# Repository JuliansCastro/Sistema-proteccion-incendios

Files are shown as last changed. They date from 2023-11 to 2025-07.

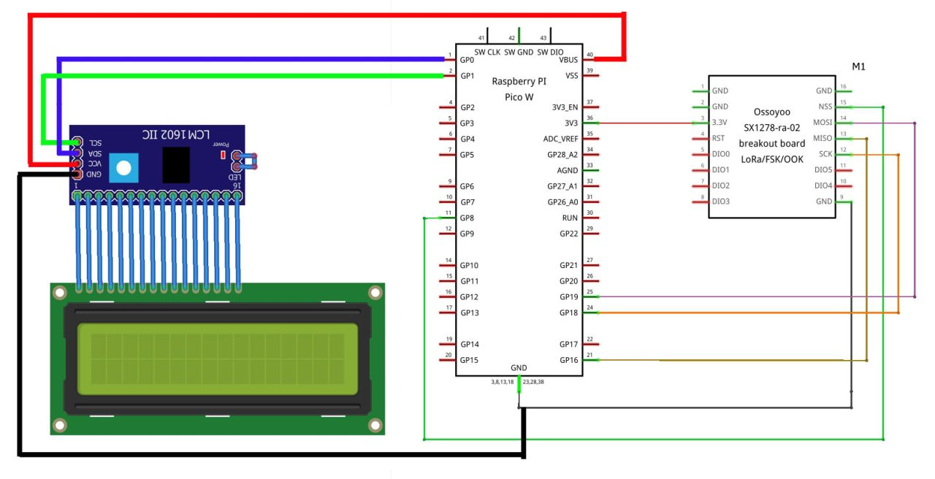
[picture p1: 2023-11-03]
imgs/image.png

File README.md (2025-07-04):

# Sistema de Protección contra Incendios con LoRa y Raspberry Pi Pico

## Resumen

Este proyecto desarrolla un sistema integral de monitoreo y protección contra incendios forestales utilizando tecnología IoT. El sistema emplea sensores distribuidos que se comunican mediante protocolo LoRa para detectar condiciones ambientales críticas (temperatura, humedad y presencia de llamas) y transmitir los datos a una estación central basada en Raspberry Pi Pico W que proporciona interfaz web para visualización en tiempo real.

## Características Principales

- **Monitoreo Distribuido**: Red de sensores inalámbricos con comunicación LoRa de largo alcance
- **Detección Multiparamétrica**: Sensores de temperatura (DHT11), humedad relativa y detector PIR para llamas
- **Comunicación Robusta**: Protocolo LoRa a 433MHz con alcance de varios kilómetros
- **Interfaz Web**: Servidor HTTP integrado en Raspberry Pi Pico W para visualización remota
- **Display Local**: Pantalla LCD I2C para monitoreo local de datos
- **Alertas en Tiempo Real**: Detección automática de condiciones de riesgo de incendio
- **Arquitectura Modular**: Diseño escalable para múltiples nodos sensores
- **Bajo Consumo**: Optimizado para aplicaciones de campo con alimentación autónoma

## Arquitectura del Sistema

```text
┌─────────────────┐       LoRa 433MHz      ┌──────────────────────┐
│   Nodo Sensor   │ ◄────────────────────► │  Estación Central    │
│  (Tx - Pico)    │                        │  (Rx - Pico W)       │
├─────────────────┤                        ├──────────────────────┤
│ • DHT11         │                        │ • LoRa Receptor      │
│ • PIR Sensor    │                        │ • WiFi Server        │
│ • LoRa Tx       │                        │ • LCD Display        │
│ • Raspberry     │                        │ • Raspberry Pi       │
│   Pi Pico       │                        │   Pico W             │
└─────────────────┘                        └──────────────────────┘
                                                      │
                                                      │ WiFi
                                                      ▼
                                           ┌──────────────────────┐
                                           │   Cliente Web        │
                                           │ (Navegador/App)      │
                                           └──────────────────────┘
```

### Componentes del Sistema

1. **Nodo Transmisor (Tx)**:
   - Raspberry Pi Pico como microcontrolador principal
   - Sensor DHT11 para temperatura y humedad
   - Sensor PIR para detección de movimiento/llamas
   - Módulo LoRa para transmisión de datos
   - Encapsulado 3D impreso para protección ambiental

2. **Estación Receptora (Rx)**:
   - Raspberry Pi Pico W con conectividad WiFi
   - Módulo LoRa para recepción de datos
   - Display LCD I2C 16x2 para visualización local
   - Servidor web HTTP integrado
   - Procesamiento y almacenamiento temporal de datos

3. **Protocolo de Comunicación**:
   - LoRa a 433MHz para comunicación de largo alcance
   - Estructura de paquetes con ID de nodo, datos de sensores y verificación
   - Interfaz web HTTP para acceso remoto

## Tecnologías Utilizadas

### Hardware

- **Microcontroladores**:
  - Raspberry Pi Pico (RP2040)
  - Raspberry Pi Pico W (RP2040 + WiFi)
- **Sensores**:
  - DHT11 (Temperatura y Humedad)
  - PIR Sensor (Detección de movimiento/llamas)
- **Comunicación**:
  - Módulos LoRa SX1276/SX1278 (433MHz)
  - WiFi integrado (Pico W)
- **Display**: LCD I2C 16x2 con controlador PCF8574
- **PCB**: Diseño personalizado en KiCad
- **Encapsulado**: Carcasas 3D impresas en PLA/PETG

### Software

- **Lenguajes**: C++ (Arduino Framework)
- **Librerías**:
  - `LoRa.h` - Comunicación LoRa
  - `DHT.h` - Sensor de temperatura/humedad
  - `WiFi.h` - Conectividad inalámbrica
  - `LiquidCrystal_I2C.h` - Control de display
  - `TimeLib.h` - Manejo de tiempo
- **Protocolos**: HTTP, LoRa, I2C, SPI
- **IDE**: Arduino IDE con soporte para RP2040
- **Herramientas de Diseño**:
  - KiCad (Diseño de PCB)
  - Fusion 360 (Modelado 3D)

## Instalación y Configuración

### Requisitos de Hardware

- 2x Raspberry Pi Pico (1x estándar, 1x Pico W)
- 2x Módulos LoRa SX1276/SX1278
- 1x Sensor DHT11
- 1x Sensor PIR
- 1x Display LCD I2C 16x2
- Componentes electrónicos (resistencias, capacitores, conectores)
- PCBs personalizadas o protoboard
- Carcasas 3D impresas
- Fuentes de alimentación (baterías o adaptadores)

### Montaje y Conexiones

#### Nodo Transmisor (Pico)

```text
DHT11:
- VCC → 3.3V
- GND → GND  
- DATA → GPIO 28

PIR Sensor:
- VCC → 5V
- GND → GND
- OUT → GPIO 27

LoRa Module:
- VCC → 3.3V
- GND → GND
- NSS → GPIO 8
- RST → GPIO 9
- DIO0 → GPIO 7
- SCK → GPIO 18
- MISO → GPIO 16
- MOSI → GPIO 19
```

#### Estación Receptora (Pico W)

```text
LoRa Module:
- (Mismas conexiones que Tx)

LCD I2C:
- VCC → 3.3V
- GND → GND
- SDA → GPIO 0
- SCL → GPIO 1
```

### Instalación del Entorno de Software

1. **Configurar Arduino IDE**:

```bash
# Instalar Arduino IDE desde: https://www.arduino.cc/en/software

# Agregar soporte para RP2040:
# File → Preferences → Additional Board Manager URLs
# Agregar: https://github.com/earlephilhower/arduino-pico/releases/download/global/package_rp2040_index.json

# Tools → Board → Boards Manager
# Buscar "pico" e instalar "Raspberry Pi Pico/RP2040"
```

2. **Instalar Librerías Requeridas**:

```bash
# En Arduino IDE: Tools → Manage Libraries
# Instalar:
- DHT sensor library by Adafruit
- LoRa by Sandeep Mistry  
- LiquidCrystal I2C by Frank de Brabander
- Time by Michael Margolis
```

3. **Configurar Red WiFi**:

```cpp
// Editar en RPi_Pico_W_Lora_Rx.ino:
#define SSID "TU_RED_WIFI"
#define PASSWORD "TU_CONTRASEÑA"
```

4. **Cargar Firmware**:

```bash
# 1. Conectar Raspberry Pi Pico manteniendo presionado BOOTSEL
# 2. Seleccionar Board: "Raspberry Pi Pico" o "Raspberry Pi Pico W"
# 3. Cargar RPi_Pico_Lora_Tx.ino en el nodo transmisor
# 4. Cargar RPi_Pico_W_Lora_Rx.ino en la estación receptora
```

## Despliegue

### Ejecución Local

1. **Inicializar Sistema**:
   - Encender nodo transmisor (comenzará a enviar datos cada 20 segundos)
   - Encender estación receptora
   - Verificar conexión LoRa en monitor serial
   - Confirmar conexión WiFi y obtener IP local

2. **Acceso a Interface Web**:
   - Conectarse a la misma red WiFi que el Pico W
   - Abrir navegador en `http://[IP_DEL_PICO_W]`
   - La página se actualiza automáticamente cada 5 segundos

3. **Monitoreo Local**:
   - Visualizar datos en tiempo real en LCD
   - Revisar logs en monitor serial (115200 baud)

### Despliegue en Campo

1. **Preparación**:
   - Instalar nodos en ubicaciones estratégicas
   - Configurar alimentación autónoma (paneles solares/baterías)
   - Verificar cobertura LoRa entre nodos

2. **Red WiFi de Campo**:
   - Configurar hotspot móvil o router portable
   - Ajustar configuración WiFi en código según disponibilidad

## Casos de Uso

### Monitoreo Forestal

```text
Escenario: Bosque de 10 km²
- 5 nodos transmisores distribuidos estratégicamente
- 1 estación central con conectividad satelital/celular
- Alertas automáticas cuando temperatura > 35°C y humedad < 30%
- Detección temprana de focos de incendio mediante sensores PIR
```

### Instalaciones Industriales

```text
Escenario: Almacén de materiales inflamables
- Nodos en cada sector crítico
- Integración con sistemas de extinción automática
- Dashboard web para personal de seguridad
- Registro histórico de condiciones ambientales
```

### Agricultura de Precisión

```text
Escenario: Invernaderos automatizados
- Monitoreo continuo de microclima
- Optimización de sistemas de riego
- Prevención de condiciones de estrés térmico
- Alertas de condiciones anómalas
```

## Estructura del Proyecto

```text
Sistema-proteccion-incendios/
├── README.md
├── Carcasa - Fusion360/           # Modelos 3D de encapsulados
│   ├── 3D/                        # Archivos STL para impresión
│   └── Fusion360/                 # Archivos fuente F3D
├── Diseño electrónico - PCB KiCad/ # Diseños de circuitos impresos
│   ├── sys_incendios_rx/          # PCB para receptor
│   ├── sys_incendios_Tx/          # PCB para transmisor
│   └── Fab_PCB_diseno/            # Archivos Gerber para fabricación
├── Software microcontroladores/    # Código fuente
│   ├── RPi_Pico_Lora_Tx/         # Firmware nodo transmisor
│   └── RPi_Pico_W_Lora_Rx/       # Firmware estación receptora
├── Docs/                          # Documentación técnica
│   ├── BOOM Materials.xlsx        # Lista de materiales
│   └── Datasheets/                # Hojas de datos de componentes
└── imgs/                          # Imágenes del proyecto
```

## Desarrollo Futuro

- [ ] Integración con bases de datos (SQLite/MySQL)
- [ ] API REST para integración con terceros
- [ ] Aplicación móvil nativa
- [ ] Protocolo MQTT para IoT
- [ ] Integración con servicios en la nube (AWS IoT, Azure IoT)
- [ ] Algoritmos de machine learning para predicción
- [ ] Soporte para más tipos de sensores
- [ ] Mesh networking con múltiples receptores

## Contribuciones

Las contribuciones son bienvenidas. Para cambios importantes:

1. Fork el proyecto
2. Crear una rama para tu feature (`git checkout -b feature/AmazingFeature`)
3. Commit tus cambios (`git commit -m 'Add some AmazingFeature'`)
4. Push a la rama (`git push origin feature/AmazingFeature`)
5. Abrir un Pull Request

## Licencia

Este proyecto está licenciado bajo la Licencia MIT - ver el archivo [LICENSE](LICENSE) para detalles.

## Créditos y Autores

**Equipo de Desarrollo:**

- **Julian A. Castro** - *Líder del proyecto* - [juacastropa@unal.edu.co](mailto:juacastropa@unal.edu.co)
- **Daniela V. Amaya** - *Desarrollo de hardware*
- **Sebastian A. Moreno** - *Desarrollo de software*
- **Javier L. Rodríguez** - *Diseño mecánico*

**Institución:** Universidad Nacional de Colombia  
**Materia:** Diseño de Sistemas Electrónicos  
**Año:** 2023

---

## Agradecimientos

- Comunidad Arduino y Raspberry Pi Foundation
- Desarrolladores de las librerías utilizadas
- Universidad Nacional de Colombia por el apoyo académico

---

*Para soporte técnico o consultas, contactar al equipo de desarrollo a través de los emails proporcionados.*

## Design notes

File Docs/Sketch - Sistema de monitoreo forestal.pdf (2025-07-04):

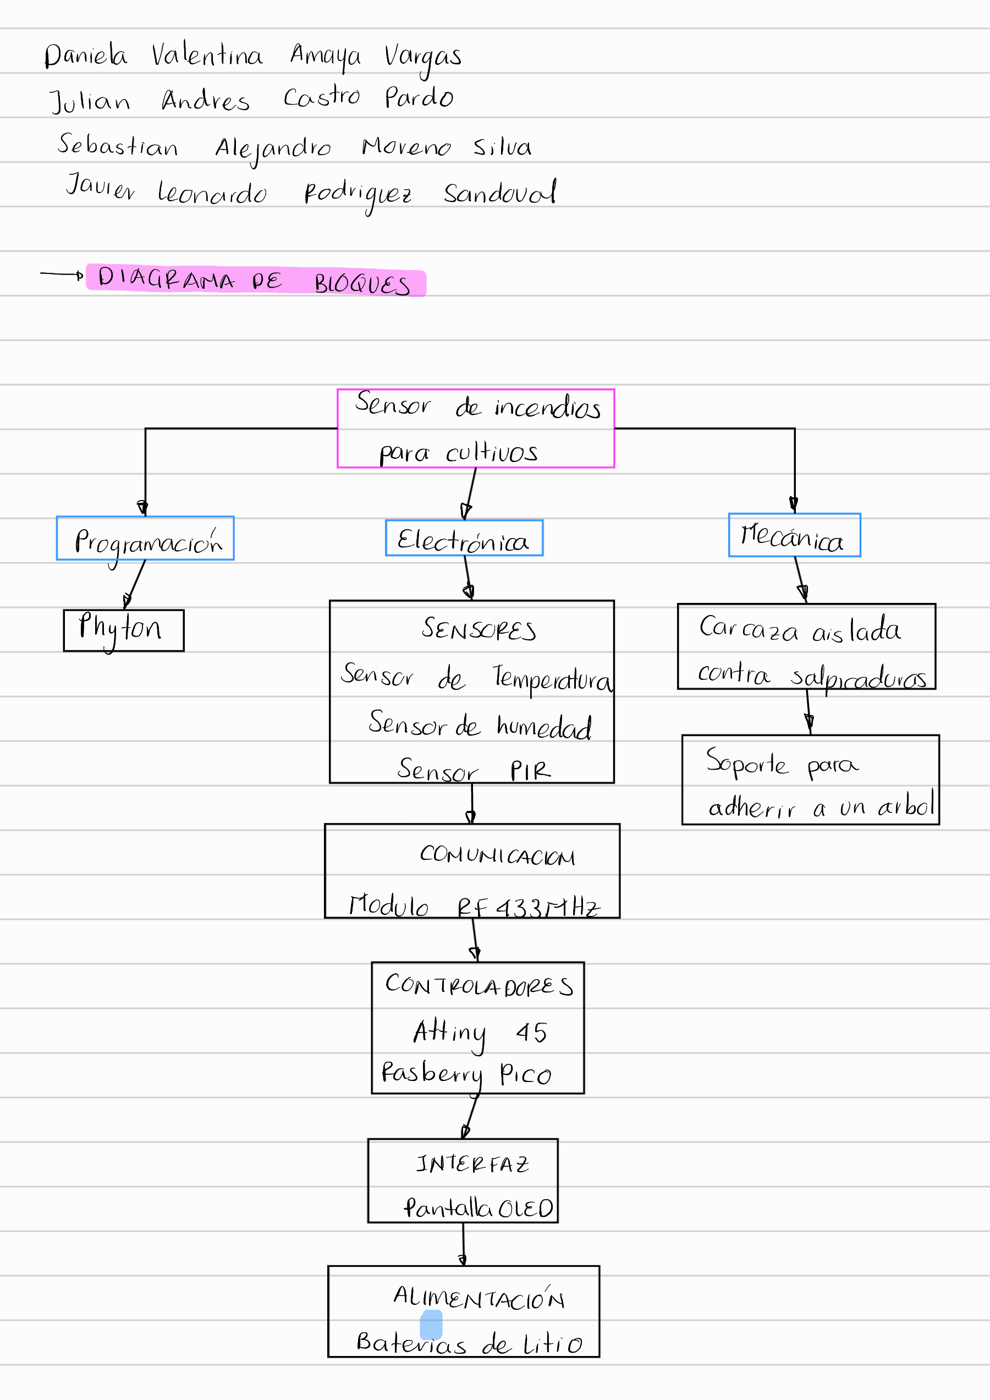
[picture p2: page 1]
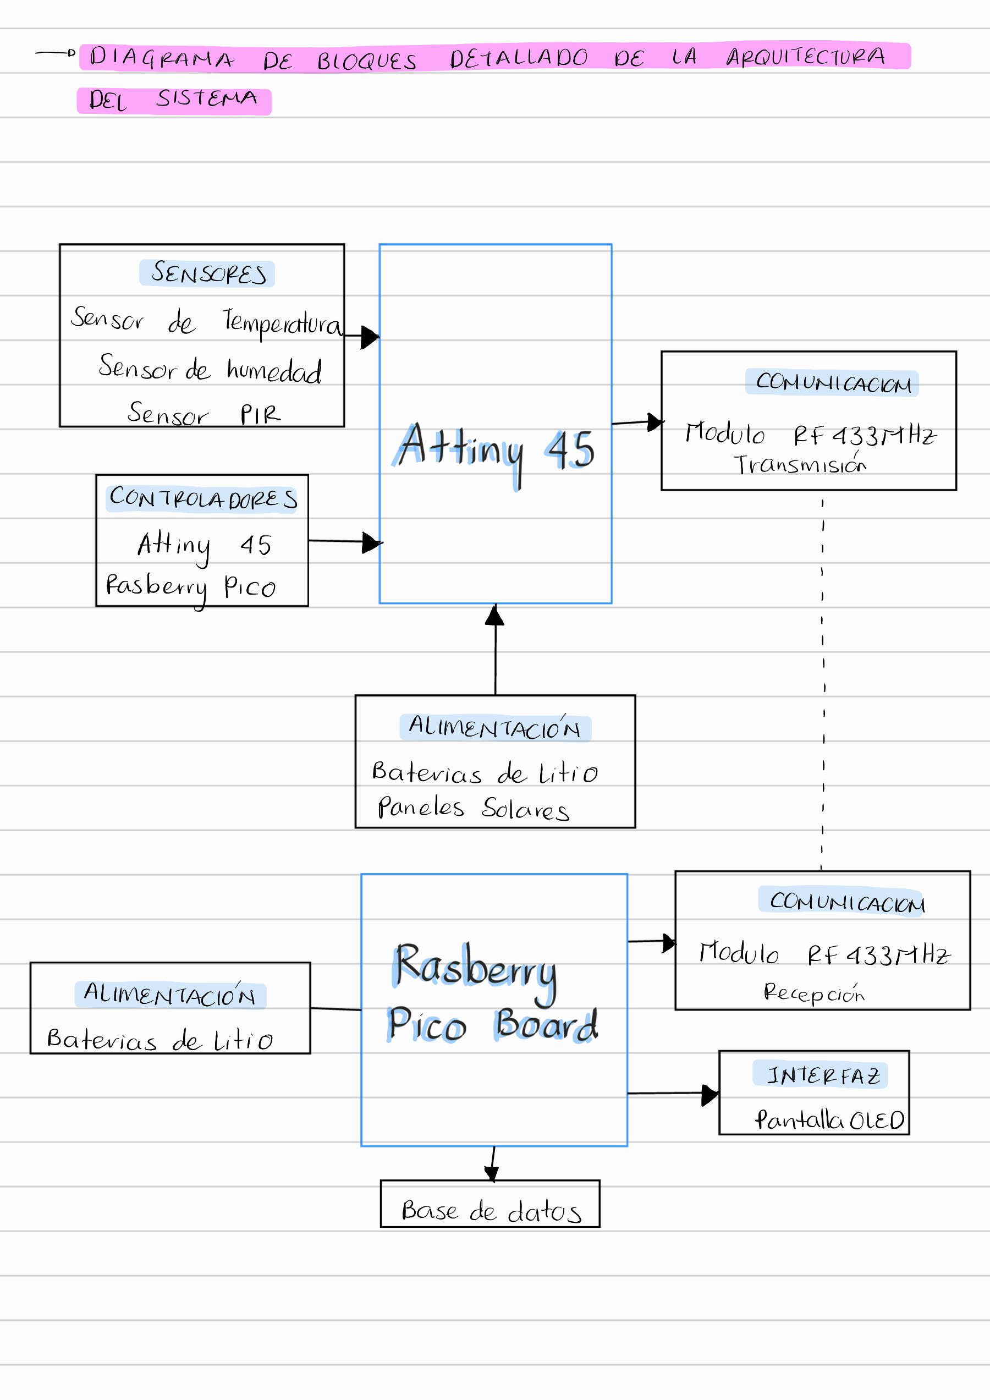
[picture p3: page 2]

Solicitudes del proyecto
Solicitud | Nombre | Descripción
Sol 001 | Monitoreo de temperatura y humedad | El dispositivo está equipado con sensores de alta precisión que permiten medir de manera constante la temperatura y la humedad del entorno circundante. Esto proporciona datos valiosos para comprender y controlar las condiciones ambientales en bosques u otros entornos exteriores
Sol 002 | Transmisión de información por RF | Utiliza tecnología de radiofrecuencia para transmitir los datos recopilados de temperatura y humedad de manera inalámbrica a una estación base o un centro de monitoreo central. Esto permite una comunicación eficiente y en tiempo real sin necesidad de cables
Sol 003 | Alimentación auxiliar por energia fotovoltaica | El dispositivo cuenta con paneles solares integrados que aprovechan la energía solar para alimentar sus operaciones. Esta fuente de energía sostenible reduce la dependencia de baterías convencionales y garantiza un funcionamiento prolongado sin intervención humana.
Sol 004 | Dispositivo resistente a salpicaduras | El diseño del dispositivo incluye materiales y carcasas que son resistentes a la exposición a la humedad y a las salpicaduras de agua. Esto asegura que el dispositivo pueda operar de manera confiable en condiciones climáticas adversas sin daños.
Sol 005 | Diseño compacto y no invasivo | El dispositivo se ha diseñado para ser compacto y liviano, lo que permite su fácil transporte y colocación en diferentes ubicaciones dentro del bosque o el entorno a monitorear. Además, se ha diseñado para minimizar su impacto en el entorno natural, evitando perturbar la flora y fauna locales.
Sol 006 | Dispositivo no contaminante | Se han tenido en cuenta consideraciones ambientales en todo el diseño del dispositivo, utilizando materiales no contaminantes y procesos de fabricación sostenibles. El objetivo es garantizar que el dispositivo no tenga un impacto negativo en el entorno que se está monitoreando
Sol 007 | Interfaz amigable con el usuario | El dispositivo está equipado con una interfaz de usuario intuitiva, que puede ser accesible a través de una aplicación móvil o una plataforma en línea. Esto facilita a los usuarios la visualización de los datos recopilados y la configuración del dispositivo según sea necesario.
Sol 008 | Dispositivo economicamente viable | Este dispositivo debe ser accesible a nivel economico, de esta forma que el proyecto se pueda implementar en cualquier zona aislada o de dificil acceso

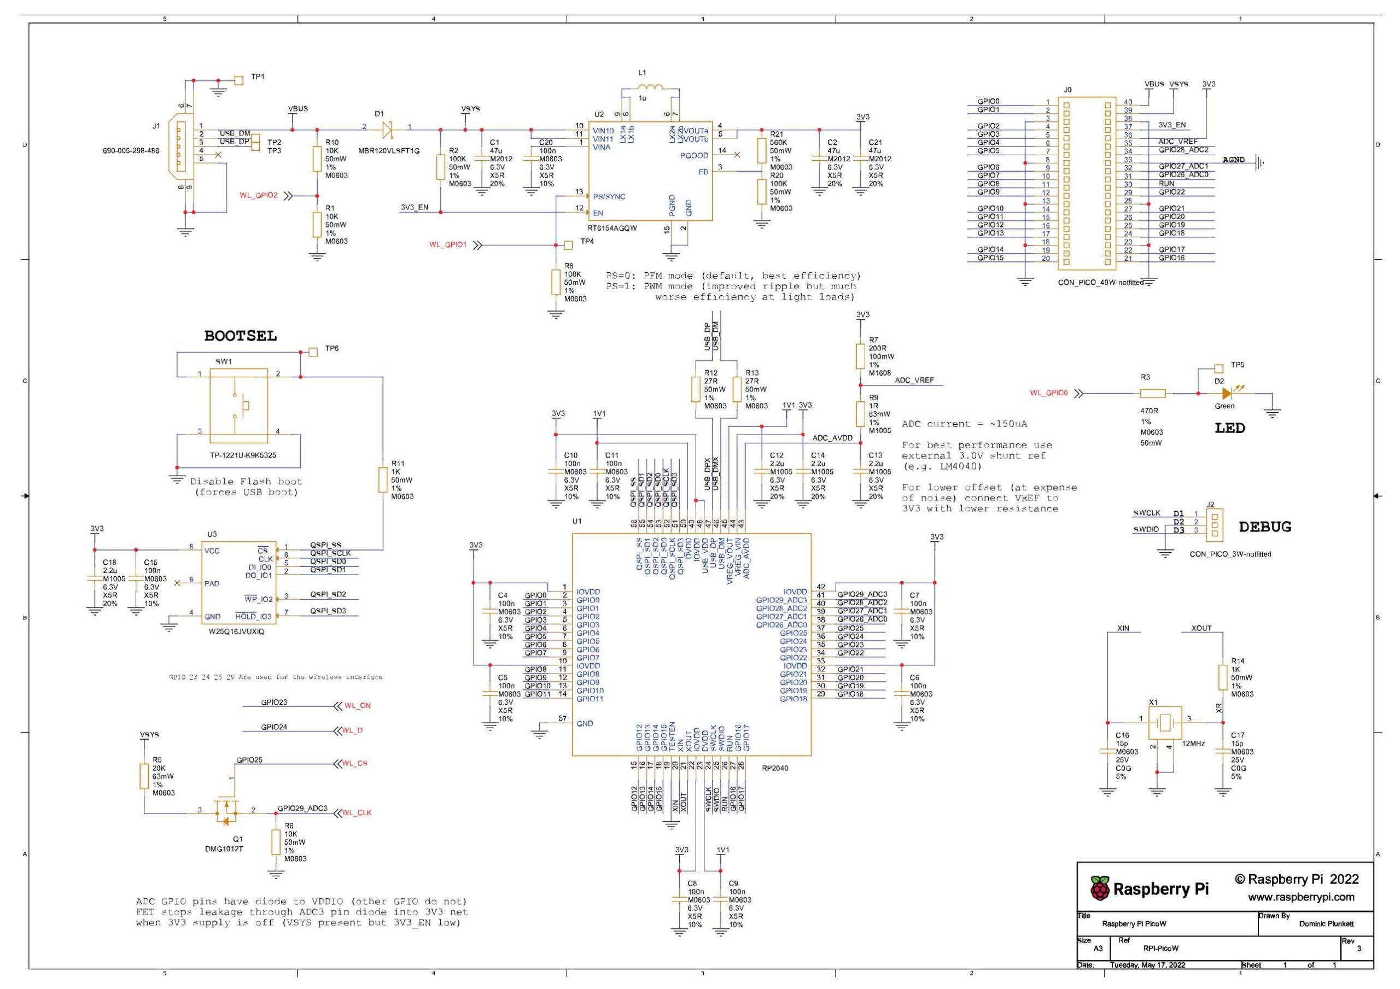
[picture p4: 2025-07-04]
Docs/Raspberry Pi/Raspberry Pi Pico W/Raspberry-pi-pico-w-schematic-1-scaled.jpg

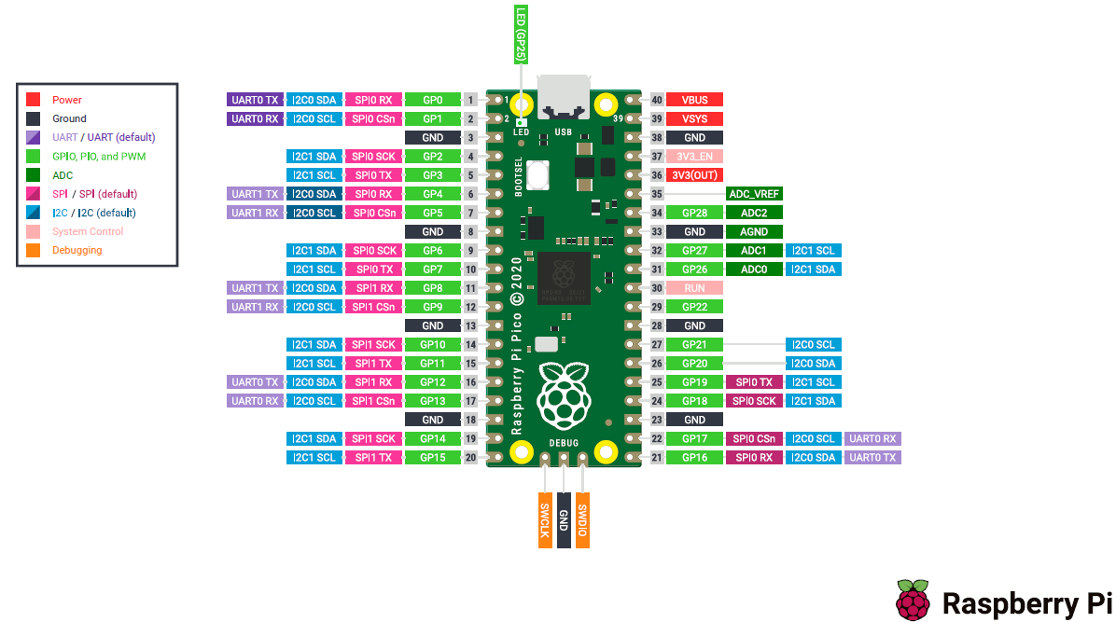
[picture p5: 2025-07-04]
imgs/Rasbnerry-Pi-Pico-Pinout.png

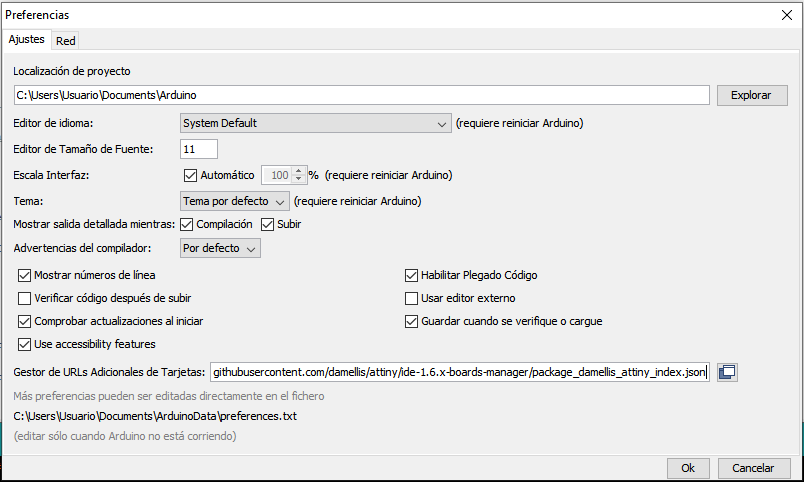
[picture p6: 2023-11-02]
imgs/URL_gestor_tarjetas.png

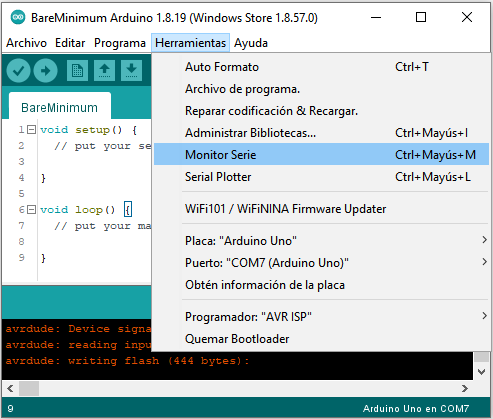
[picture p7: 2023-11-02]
imgs/BareMinimum.png

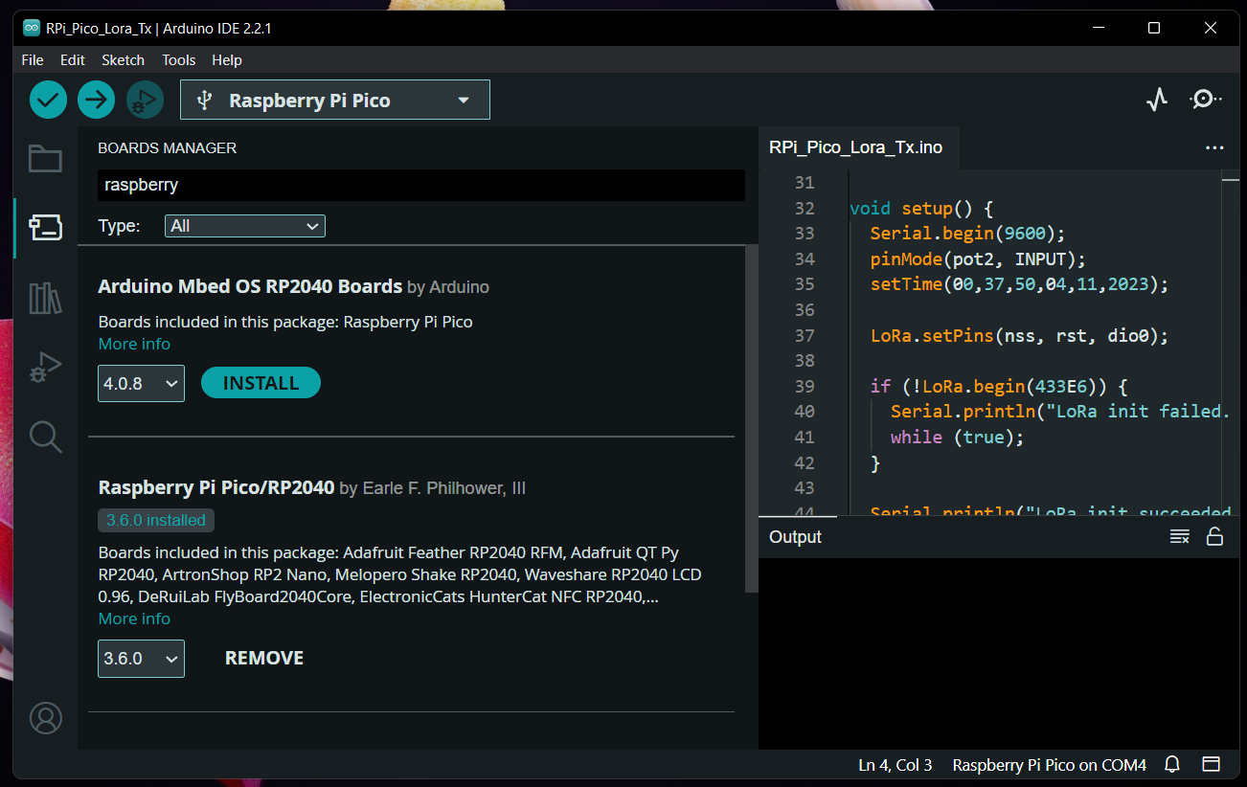
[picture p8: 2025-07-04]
imgs/paquete tarjeta RPi pico arduino.png

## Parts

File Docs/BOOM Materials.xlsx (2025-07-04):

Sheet: Presupuesto
PRESUPUESTO
Componente | Valor C/U | Cantidad | Total | Link o Ref | Gasto de | TOTAL | $270300
PLA | 100 | 220 | 22000 |  | N - Profe | Cada uno | $50850
Sockets pin 1.27mm | 2000 | 5 | 10000 |  | N - Julian
Portabatería | 2500 | 1 | 2500 |  | N - Sebas
Regulador 5V | 3900 | 1 | 3900 |  | N - Julian | Gastos de cada uno |  | Pendiente
Jumpers | 5000 | 1 | 5000 |  | N - Julian | Julian | $132500 | -
Impresión 3D | 5000 | 1 | 5000 |  | N - Dani | Sebas | $18500 | $32350
Modulo de carga batt | 6000 | 1 | 6000 |  | N - Sebas | Dani | $5000 | $45850
Sensor PIR | 7900 | 1 | 7900 | https://www.zamux.co/sensor-de-movimiento-y-presencia-pir-hcsr01 | N - Julian | Javier | $49500 | $1350
Batería de Litio | 10000 | 1 | 10000 |  | N - Sebas | Profe | $42000 | $0
Panel solar 6V 100mA | 15000 | 2 | 30000 |  | N - Julian
Pantalla 2x16 | 15900 | 1 | 15900 | https://www.zamux.co/pantalla-display-lcd-2x16-azul-con-backlight-con-pines-soldados | N - Julian
Impresión PCB | 20000 | 1 | 20000 |  | N - Profe
LoRa RF | 29900 | 2 | 59800 | https://www.zamux.co/modulo-lora-ra-02-sx1278-con-base | N - Julian
Raspberry Pi pico | 39300 | 1 | 39300 | https://www.sigmaelectronica.net/producto/rpi-pico-w/ | S - Julian
Raspberry Pi pico W | 25000 | 1 | 25000 | https://www.sigmaelectronica.net/producto/raspberry-pi-pico/ | S - Julian
Tornillos | 8000 | 1 | 8000 |  | S - Julian
 |  | TOTAL | 270300
 |  | Cada uno | 50850

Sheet: Sensor RF
 | NRF24 | Lora | HC12
Voltaje | 1.9v a 3.6v
Corriente maxima | Modo TX - 11.3mA Modo RX - 12.3mA
Velocidad de transmision | 2000 kbps
Alcance sin obstaculos | 1000m
Alcance con obstaculos
Multipunto
Documentacion
Conexion rasberry
Frecuencia de operacion | 2.4MHz a 2.525MHz
Precio
Modo de conexion
link |  | https://www.zamux.co/modulo-lora-ra-02-sx1278-con-base?similar_product=true | https://www.sigmaelectronica.net/producto/hc-12/
 |  | https://circuitdigest.com/microcontroller-projects/arduino-lora-sx1278-interfacing-tutorial | https://www.allaboutcircuits.com/projects/understanding-and-implementing-the-hc-12-wireless-transceiver-module/
 |  |  | https://howtomechatronics.com/tutorials/arduino/arduino-and-hc-12-long-range-wireless-communication-module/

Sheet: Potencia requerida
 | Voltaje | Corriente en funcionamiento
Componente
Componente
PLA
#REF!
Sockets pin 1.27mm
#REF!
Portabatería
Regulador 5V
Jumpers
Impresión 3D
Modulo de carga batt
Sensor PIR
Tornillos

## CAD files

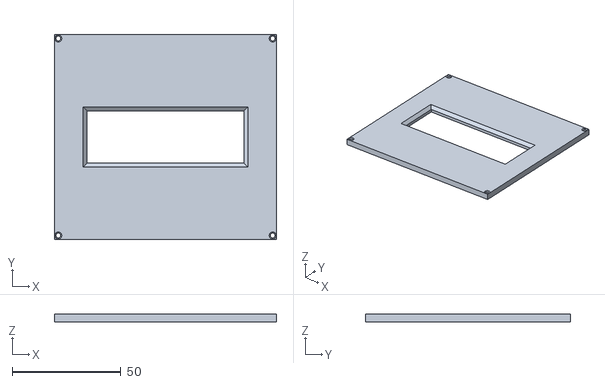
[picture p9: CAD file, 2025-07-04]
Carcasa - Fusion360/3D/CoverRx_v2.stl
102.0 x 94.0 x 3.50

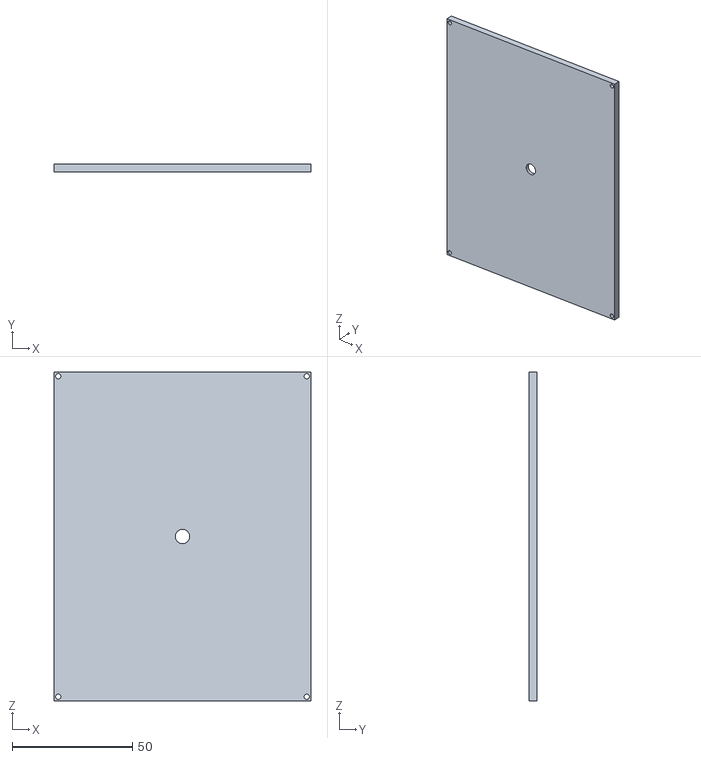
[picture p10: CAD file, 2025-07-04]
Carcasa - Fusion360/3D/CoverTx_v3.stl
107.0 x 3.50 x 137.0

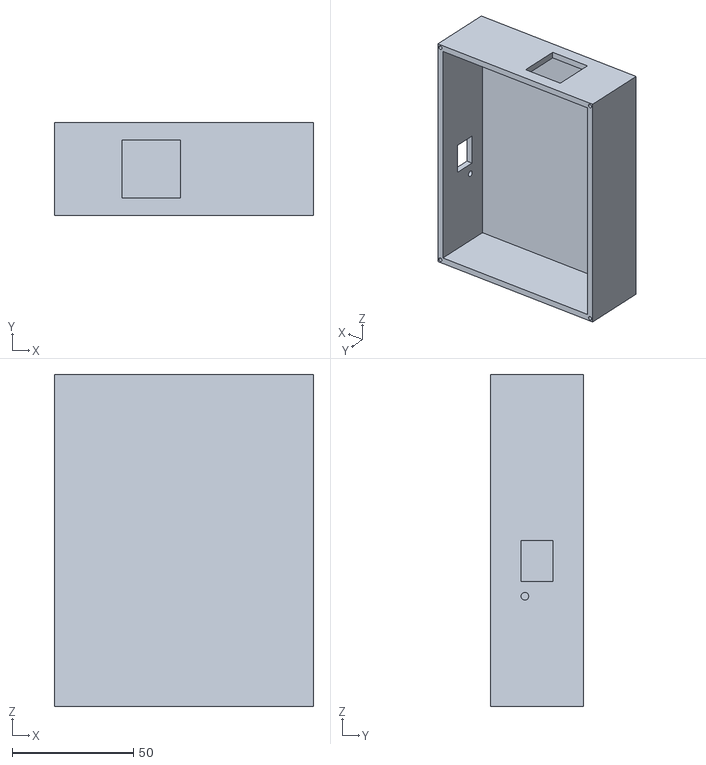
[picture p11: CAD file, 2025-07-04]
Carcasa - Fusion360/3D/FireAlarmTx_v3_Box.stl
107.0 x 38.5 x 137.0

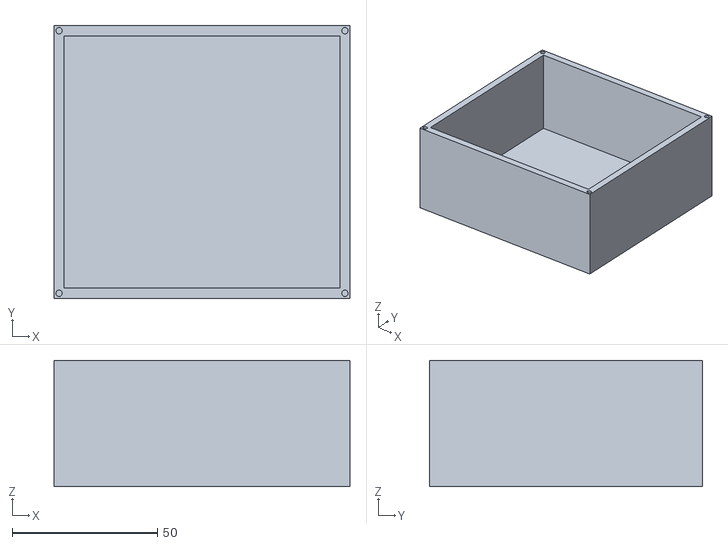
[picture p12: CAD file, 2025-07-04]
Carcasa - Fusion360/3D/FireAlarmRx_v2_Box.stl
102.0 x 94.0 x 43.5

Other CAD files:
Carcasa - Fusion360/Fusion360/FireAlarmRx v2.f3d
Carcasa - Fusion360/Fusion360/FireAlarmTx v3.f3d

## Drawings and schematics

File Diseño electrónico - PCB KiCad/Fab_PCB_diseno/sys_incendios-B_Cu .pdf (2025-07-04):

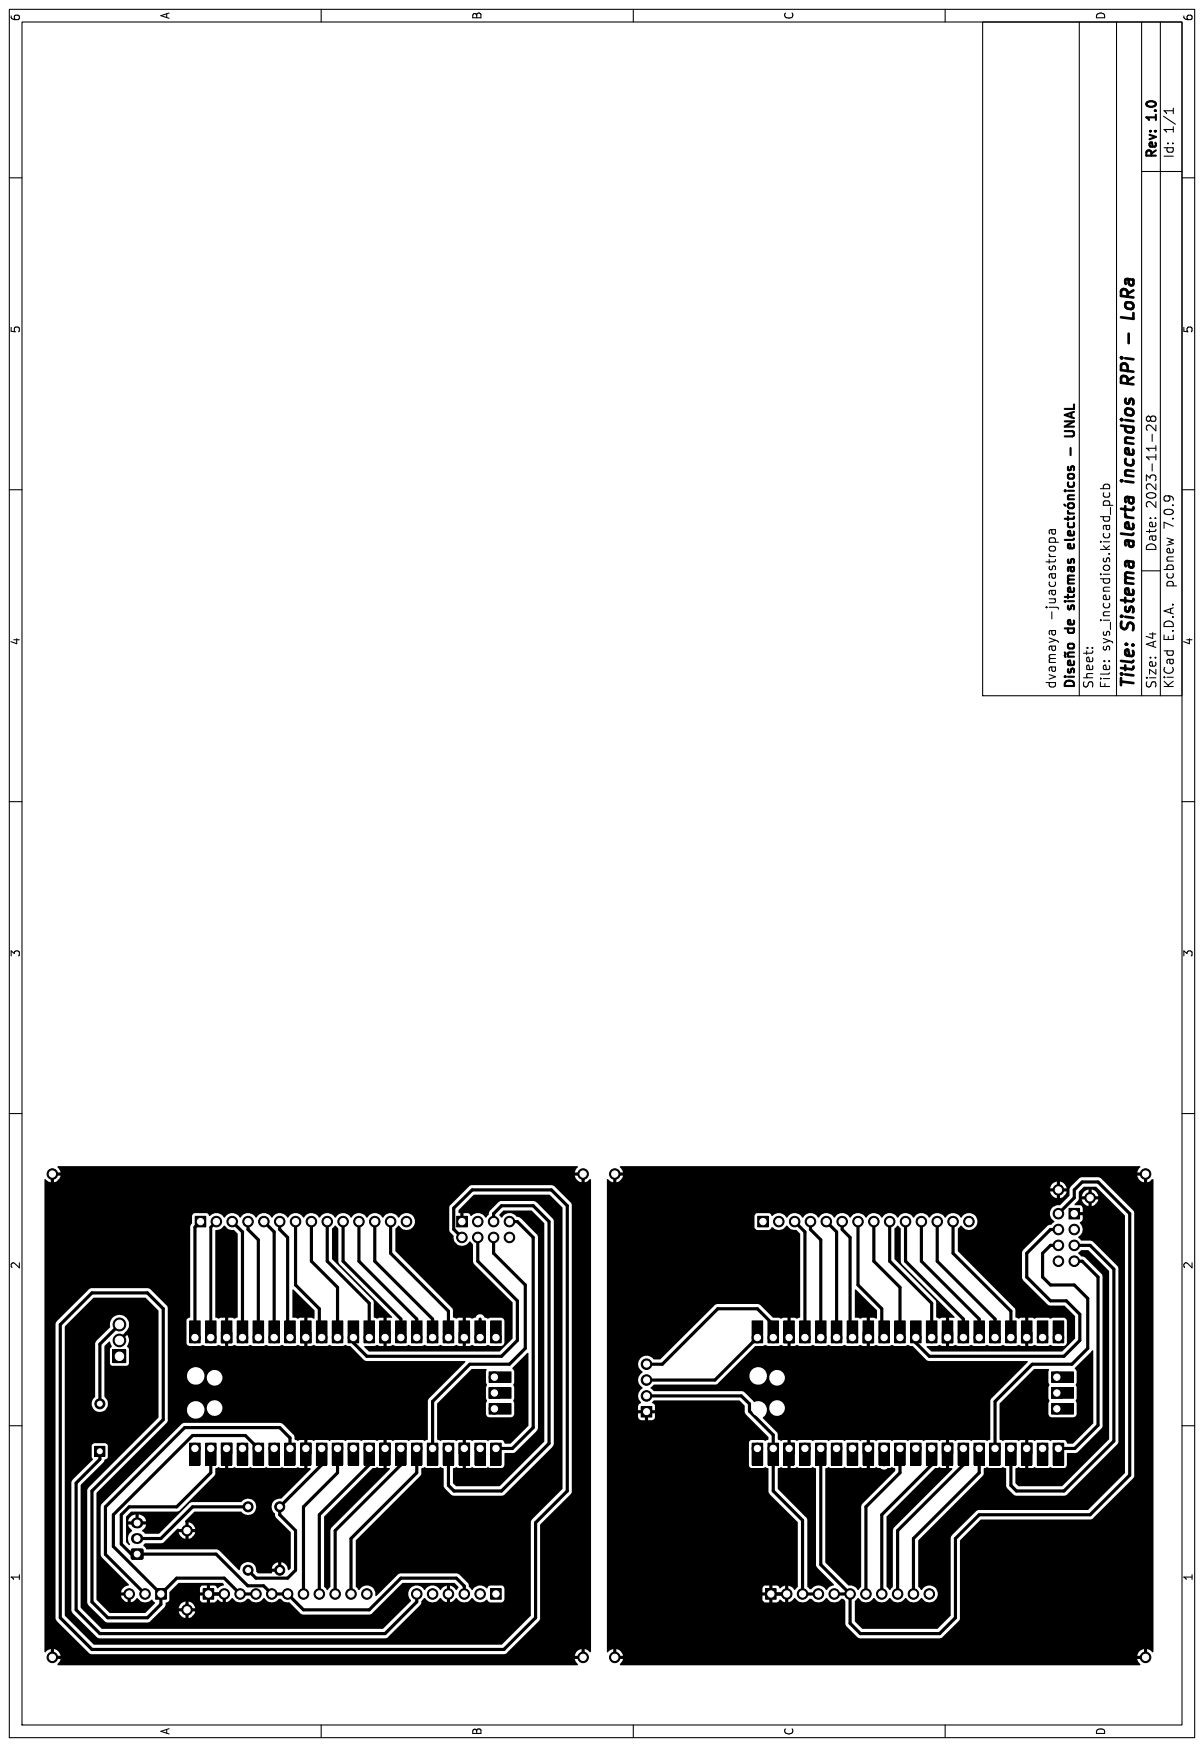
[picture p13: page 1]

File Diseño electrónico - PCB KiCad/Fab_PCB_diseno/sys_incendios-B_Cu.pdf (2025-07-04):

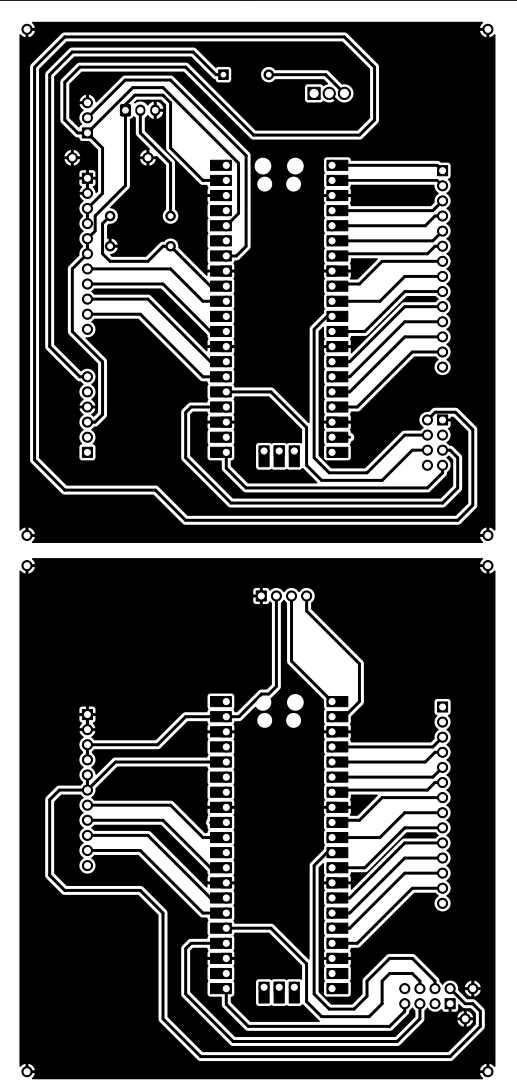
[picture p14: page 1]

Id: 1/1 Title: Sistema alerta incendios RPi - LoRa

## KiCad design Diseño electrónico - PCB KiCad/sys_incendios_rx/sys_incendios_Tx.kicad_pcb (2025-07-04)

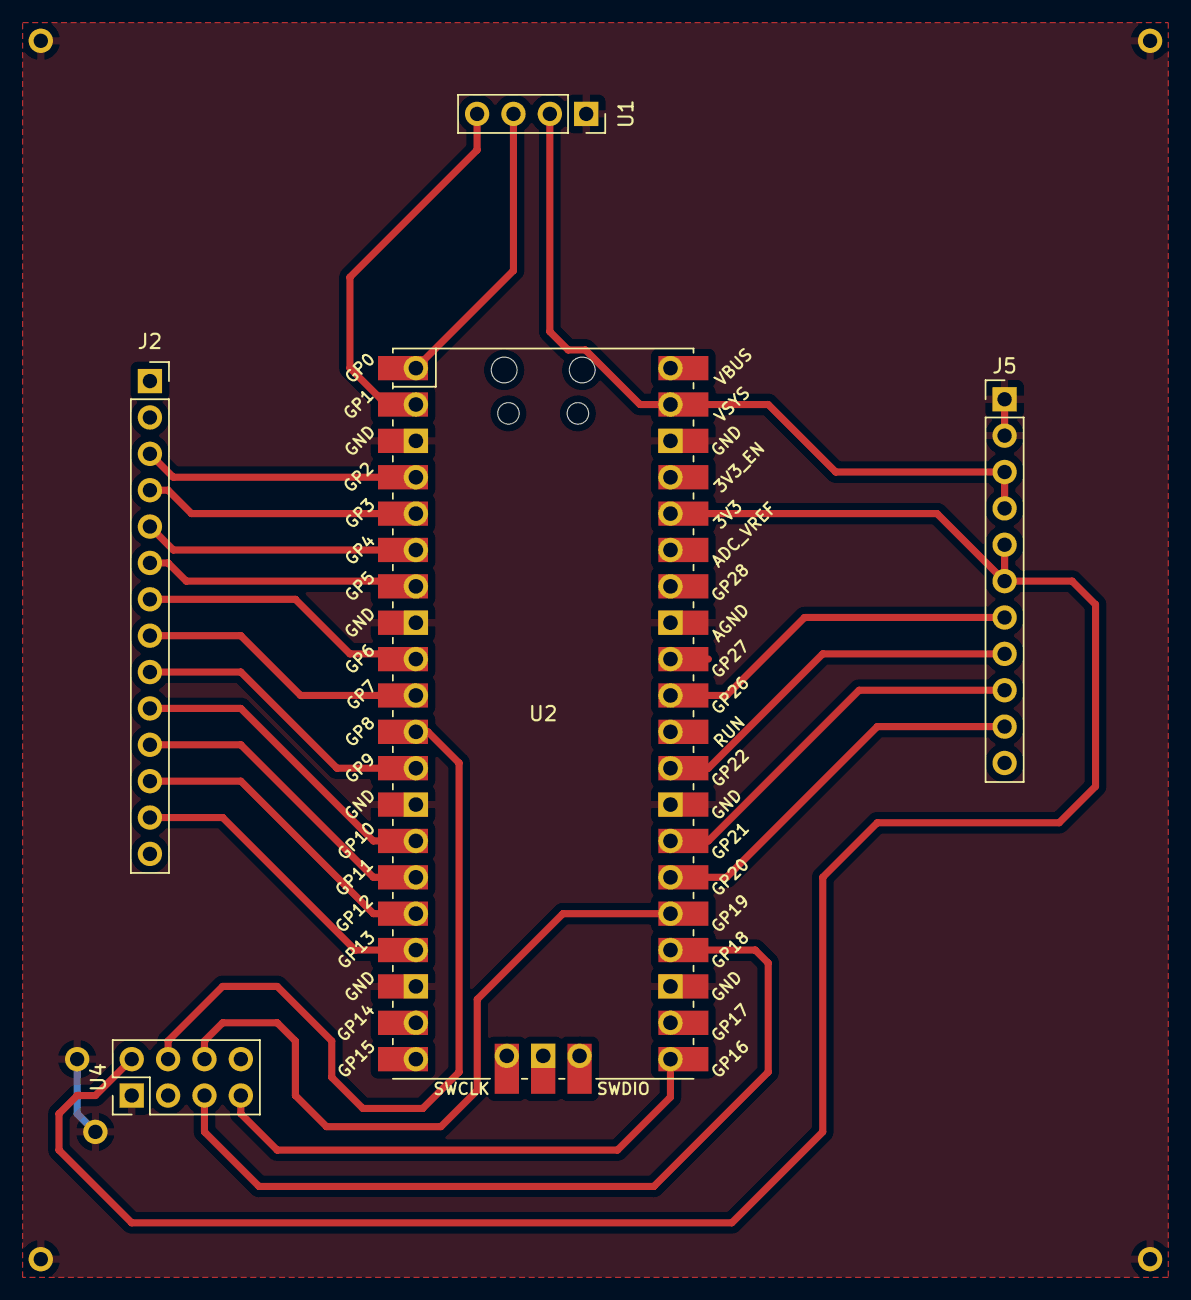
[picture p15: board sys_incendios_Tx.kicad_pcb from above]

Board: 2 copper layers, 5 parts (0 on the bottom side), 24 nets.

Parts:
J2: Conn_01x15; PinSocket_1x14_P2.54mm_Vertical
J5: Conn_01x11; PinHeader_1x11_P2.54mm_Vertical
U1: LCD-DRIVER-I2C; Conn_LCD_Driver_16X2_module
U2: Pico; RPi_Pico_SMD_TH
U4: RA-02_LORA_mod_V4.0; PinHeader_2x04_P2.54mm_Vertical

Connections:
/3.3V: J5.5, J5.6, U2.36 (3V3), U4.2 (3.3V)
/GPIO2: J2.3, U2.4 (GPIO2)
/GPIO3: J2.4, U2.5 (GPIO3)
/GPIO4: J2.5, U2.6 (GPIO4)
/GPIO5: J2.6, U2.7 (GPIO5)
/GPIO6: J2.7, U2.9 (GPIO6)
/GPIO7: J2.8, U2.10 (GPIO7)
/GPIO9: J2.9, U2.12 (GPIO9)
/GPIO10: J2.10, U2.14 (GPIO10)
/GPIO11: J2.11, U2.15 (GPIO11)
/GPIO12: J2.12, U2.16 (GPIO12)
/GPIO13: J2.13, U2.17 (GPIO13)
/GPIO20: J5.10, U2.26 (GPIO20)
/GPIO21: J5.9, U2.27 (GPIO21)
/GPIO22: J5.8, U2.29 (GPIO22)
/GPIO26: J5.7, U2.31 (GPIO26_ADC0)
/MISO: U2.21 (GPIO16), U4.7 (MISO)
/MOSI: U2.25 (GPIO19), U4.6 (MOSI)
/NSS: U2.11 (GPIO8), U4.4 (NSS)
/SCK: U2.24 (GPIO18), U4.5 (SCK)
/SCL: U1.4 (SCL), U2.2 (GPIO1)
/SDA: U1.3 (SDA), U2.1 (GPIO0)
/vcc: J5.3, J5.4, U1.2 (VCC), U2.39 (VSYS)
GND: J5.1, J5.2, U1.1 (GND), U2.3 (GND), U2.8 (GND), U2.13 (GND), U2.18 (GND), U2.23 (GND), U2.28 (GND), U2.33 (AGND), U2.38 (GND), U4.1 (GND)

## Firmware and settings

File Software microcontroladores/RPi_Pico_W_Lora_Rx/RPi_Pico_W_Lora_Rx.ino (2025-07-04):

/*
  Raspberry pi pico w LoRa receiver with server WiFi
  juacastropa@unal.edu.co
*/

#include <SPI.h>
#include <LoRa.h>
#include <Wire.h>
#include <WiFi.h>
#include <LiquidCrystal_I2C.h>

#define PCF8574 0x27  // LCD Addres
#define PCF8574A 0x3F
#define dio0 7  // Pinboard 10
#define nss 8   // Pinboard 11
#define rst 9   // Pinboard 12
#define SDA 0   // Pinboard 1
#define SCL 1   // Pinboard 2

#define SSID "Maxwell"       // Put your WifiSSID here
#define PASSWORD "a1b2c3d7"  // Put your wifi password here
#define t_Delay 500

//LCD
TwoWire Wire_00(i2c0, SDA, SCL);
LiquidCrystal_I2C lcd(&Wire_00, PCF8574, 16, 2);

WiFiServer server(80);  // Set web server port number to 80
String header;          // Variable to store the HTTP request

String picoLEDState = "off";  // Variable to store onboard LED state

unsigned long currentTime = millis();  // Current time
unsigned long previousTime = 0;        // Previous time
const long timeoutTime = 2000;         // Define timeout time in milliseconds (example: 2000ms = 2s)

// outgoing message
byte msgCount = 0;  // count of outgoing messages
byte MasterNode = 0xFF;
byte Node2 = 0xCC;

String node = "";
String hum = "";
String temp = "";
String pir = "";
String flame = "";

void setup() {
  Serial.begin(115200);
  Wire_00.begin();
  Wire_00.setClock(100000);  // 100kHz
  lcd.begin();
  lcd.backlight();
  lcd.print("LCD beging!");

  pinMode(LED_BUILTIN, OUTPUT);    // Initialize the LED as an output
  digitalWrite(LED_BUILTIN, LOW);  // Set LED off

  LoRa.setPins(nss, rst, dio0);
  if (!LoRa.begin(433E6)) {  // initialize ratio at 433 MHz
    Serial.println("LoRa init failed. Check your connections.");
    while (true)
      ;  // if failed, do nothing
  }
  Serial.println("LoRa init succeeded.");
  lcd.clear();
  lcd.print("LoRa init succeeded.");
  delay(t_Delay);

  WiFi.begin(SSID, PASSWORD);  // Connect to Wi-Fi network with SSID and password

  // Display progress on Serial monitor
  Serial.print("Wait WiFi ...");
  lcd.clear();
  lcd.print("Wait WiFi ...");
  while (WiFi.status() != WL_CONNECTED) {
    delay(500);
    Serial.print(".");
    lcd.setCursor(0, 1);
    lcd.print(".");
  }

  // Print local IP address and start web server. Default: http://192.168.33.141/
  Serial.println("");
  Serial.print("WiFi connected at IP Address ");
  Serial.println(WiFi.localIP());
  lcd.clear();
  lcd.print("WiFi connected at IP Address ");
  lcd.setCursor(0, 1);
  lcd.print(WiFi.localIP());
  delay(5000);

  // Start Server
  server.begin();
}

void loop() {
  LoRaOnReceive(LoRa.parsePacket());  // parse for a packet, and call onReceive with the result
  WiFiServer(server.available());     // Listen for incoming clients
}

void LoRaOnReceive(int packetSize) {
  if (packetSize == 0) return;  // if there's no packet, return

  // read packet header bytes:
  int recipient = LoRa.read();           // recipient address
  byte sender = LoRa.read();             // sender address
  byte incomingMsgId = LoRa.read();      // incoming msg ID
  byte incomingMsgLength = LoRa.read();  // incoming msg length

  String incomingMsg = "";

  while (LoRa.available()) {
    incomingMsg += (char)LoRa.read();
  }

  if (incomingMsgLength != incomingMsg.length()) {  // check length for error
    // Serial.println("error: message length does not match length");
    return;  // skip rest of function
  }

  // if the recipient isn't this device or broadcast,
  if (recipient != Node2 && recipient != MasterNode) {
    //Serial.println("This message is not for me.");
    return;  // skip rest of function
  }

  Serial.println("Incoming Msg: " + incomingMsg);
  //lcd.print(incomingMsg);

  node = getValue(incomingMsg, ',', 0);
  hum = getValue(incomingMsg, ',', 1);
  temp = getValue(incomingMsg, ',', 2);
  pir = getValue(incomingMsg, ',', 3);

  lcd.clear();
  lcd.print("Nodo: ");
  lcd.setCursor(0, 1);
  lcd.print(node);
  delay(t_Delay);

  /*
  float tempValue = temp.toFloat();
  int humValue = hum.toInt();
  int pirValue = pir.toInt();

  Serial.println(tempValue);
  Serial.println(humValue);
  Serial.println(pirValue);
  incomingMsg = ""; 
  */

  lcd.clear();
  lcd.print("Humedad: ");
  lcd.setCursor(0, 1);
  lcd.print(hum);
  delay(t_Delay);

  lcd.clear();
  lcd.print("Temperatura: ");
  lcd.setCursor(0, 1);
  lcd.print(temp);
  delay(t_Delay);

  if (pir == "0") {  //Flame sensor detected == 0
    flame = "Flame detected";
    lcd.clear();
    lcd.print("PIR: ");
    lcd.setCursor(0, 1);
    lcd.print(flame);
    Serial.println(flame);
    delay(t_Delay);
  }
  else{
    flame = "No flames";
  }
}


String getValue(String data, char separator, int index) {
  int found = 0;
  int strIndex[] = { 0, -1 };
  int maxIndex = data.length() - 1;

  for (int i = 0; i <= maxIndex && found <= index; i++) {
    if (data.charAt(i) == separator || i == maxIndex) {
      found++;
      strIndex[0] = strIndex[1] + 1;
      strIndex[1] = (i == maxIndex) ? i + 1 : i;
    }
  }
  return found > index ? data.substring(strIndex[0], strIndex[1]) : "";
}

void WiFiServer(WiFiClient client) {  // Listen for incoming clients
  if (client) {                       // If a new client connects,
    currentTime = millis();
    previousTime = currentTime;
    Serial.println("New Client.");                                             // print a message out in the serial port
    String currentLine = "";                                                   // make a String to hold incoming data from the client
    while (client.connected() && currentTime - previousTime <= timeoutTime) {  // loop while the client's connected
      currentTime = millis();
      if (client.available()) {  // if there's bytes to read from the client,
        char c = client.read();  // read a byte, then
        Serial.write(c);         // print it out the serial monitor
        header += c;
        if (c == '\n') {  // if the byte is a newline character
          // if the current line is blank, you got two newline characters in a row.
          // that's the end of the client HTTP request, so send a response:
          if (currentLine.length() == 0) {
            // HTTP headers always start with a response code (e.g. HTTP/1.1 200 OK)
            // and a content-type so the client knows what's coming, then a blank line:
            client.println("HTTP/1.1 200 OK");
            client.println("Content-type:text/html");
            client.println("Connection: close");
            client.println();

            // Display the HTML web page
            client.println("<!DOCTYPE html><html>");
            client.println("<head><meta http-equiv=\"refresh\" content=\"5\" charset=\"utf-8\">");
            client.println("<meta name=\"viewport\" content=\"width=device-width, initial-scale=1\">");
            client.println("<link rel=\"stylesheet\" href=\"https://use.fontawesome.com/releases/v5.7.2/css/all.css\" integrity=\"sha384-fnmOCqbTlWIlj8LyTjo7mOUStjsKC4pOpQbqyi7RrhN7udi9RwhKkMHpvLbHG9Sr\" crossorigin=\"anonymous\">");
            client.println("<title>Diseño Sistemas Electrónicos</title>");

            // CSS to style the paragraph
            client.println("<style>html {");
            client.println("font-family: Arial; display: inline-block; margin: 0px auto; text-align: center;}");
            client.println("h1 { font-size: 2.0rem; }");
            client.println("p { font-size: 2.0rem; }");
            client.println(".units { font-size: 1.8rem; }");
            client.println(".names { font-size: 1.0rem; }");
            client.println(".bme-labels{ font-size: 1.5rem; vertical-align:middle; padding-bottom: 15px; }");
            client.println("</style>");
            client.println("</head>");

            // Web Page Heading
            client.println("<body>");
            client.println("<h1>Monitoring station: " + node + "</h1>");

            //client.println("<br>");
            client.println("<p>");
            client.println("<span class=\"names\">Julian A. Castro, </span>");
            client.println("<span class=\"names\">Daniela V. Amaya, </span>");
            client.println("<span class=\"names\">Sebastian A. Moreno, </span>");
            client.println("<span class=\"names\">Javier L. Rodríguez</span>");
            client.println("</p>");
            client.println("<br>");

            // Display current state of sensors
            client.println("<p>");
            client.println("<i class=\"fas fa-thermometer-half\" style=\"color:#059e8a;\"></i>");
            client.println("<span class=\"bme-labels\">Temperature:</span>");
            client.println("<span class=\"units\">" + temp + "°C </span>");
            client.println("</p>");

            client.println("<p>");
            client.println("<i class=\"fas fa-tint\" style=\"color: #00add6;\"></i>");
            client.println("<span class=\"bme-labels\">R. Humidity:</span>");
            client.println("<span class=\"units\">" + hum + "% </span>");
            client.println("</p>");

            client.println("<p>");
            client.println("<i class=\"fas fa-fire-alt\" style=\"color:#ffa500;\"></i>");  
            client.println("<span class=\"bme-labels\"></span>");
            client.println("<span>" + flame + "</span>");
            client.println("</p>");

            client.println("</body></html>");

            // The HTTP response ends with another blank line
            client.println();
            break;  // Break out of the while loop
          } else {  // if you got a newline, then clear currentLine
            currentLine = "";
          }
        } else if (c != '\r') {  // if you got anything else but a carriage return character,
          currentLine += c;      // add it to the end of the currentLine
        }
      }
    }
    // Clear the header variable
    header = "";
    // Close the connection
    client.stop();
    Serial.println("Client disconnected.");
    Serial.println("");
  }
}

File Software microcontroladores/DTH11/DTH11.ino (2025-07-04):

#include "DHT.h" //cargamos la librería DHT
#define DHTPIN 9 //Seleccionamos el pin en el que se conectará al sensor
#define DHTTYPE DHT11 //Se selecciona el DHT11
DHT dht(DHTPIN, DHTTYPE); //Se inicia una variable que será usada por Arduino para comunicarse con el sensor
void setup() {
  Serial.begin(9600); //Se inicia la comunicación serial
  dht.begin(); //Se inicia el sensor
}
void loop() {
  int h = dht.readHumidity(); //Se lee la humedad
  int t = dht.readTemperature(); //Se lee la temperatura
  //Se imprimen las variables
  Serial.print("H: ");
  Serial.println(h);
  Serial.print("T: ");
  Serial.println(t);
  delay(1000); //Se espera X segundos para seguir leyendo datos
}
